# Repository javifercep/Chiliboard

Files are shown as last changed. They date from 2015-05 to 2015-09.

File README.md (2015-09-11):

# Chiliboard
The Chiliboard is an Arduino form factor board with two CAN - 2.0B interfaces. It is based on STM32F105 MCU and can work as an extension of the [Noodleboard](https://github.com/javifercep/Noodleboard). It has been developed for the [MuBA](http://javisfryingchips.com/portfolio/detail/multi-bus-analyzer/) project.

##Features

 * STM32F105RGT6 microcontroller featuring 32-bit ARM Cortex-M3 core,256 KB Flash, 64 KB RAM in an LQFP64 package
 * Extension header fully compatible with Arduino™ form-factor
 * SN65HVD232: CAN transceiver
 * Board power supply: through pin 5 V (Arduino form-factor).
 * Four green user LEDs
 * Reset button
 * Headers for programming and debugging through SWD protocol

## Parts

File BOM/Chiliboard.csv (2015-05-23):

ref | value | footprint | Campo1 | Campo2 | Campo3 | Campo4 | Campo5 | Campo6 | Campo7 | Campo8
C1 | 18 p | ~
C2 | 18 p | ~
C3 | 1u | ~
C4 | 100n | ~
C5 | 100n | ~
C6 | 1u | ~
C7 | 100n | ~
C8 | 100n | ~
C9 | 100n | ~
C10 | 6.8p | ~
C11 | 100n | ~
C12 | 6.8p | ~
C13 | 1u | ~
C14 | 10u | ~
C15 | 10u | ~
C16 | 10u | ~
C17 | 100n | ~
C18 | 100n | ~
C29 | 100n | ~
C32 | 4u7 | ~
CON1 | SWD
D1 | DIODE | ~
D10 | LED | ~
D11 | LED | ~
D12 | LED | ~
D13 | LED | ~
IC1 | LD1117S33 | ~
J1 | DB9
J2 | DB9
JP1 | JUMPER | ~
L1 | fcm1608 | ~
R1 | 0 | ~
R2 | 0 | ~
R3 | 47 | ~
R4 | 10k | ~
R5 | 510 | ~
R6 | 0 | ~
R7 | 0 | ~
R8 | 120 | ~
R9 | 0 | ~
R10 | 120 | ~
R11 | 0 | ~
R12 | 0 | ~
R13 | 0 | ~
R14 | 0 | ~
R15 | 0 | ~
R35 | 510 | ~
R36 | 510 | ~
R37 | 680 | ~
R38 | 680 | ~
SW2 | SW_PUSH | ~
U1 | STM32F105R8 | ~
U2 | ARDUINO_UNO_REDUCED | ~
U3 | SN65HVD232
U4 | SN65HVD232
X1 | 8 MHz | ~
X2 | 32.768 kHz | ~

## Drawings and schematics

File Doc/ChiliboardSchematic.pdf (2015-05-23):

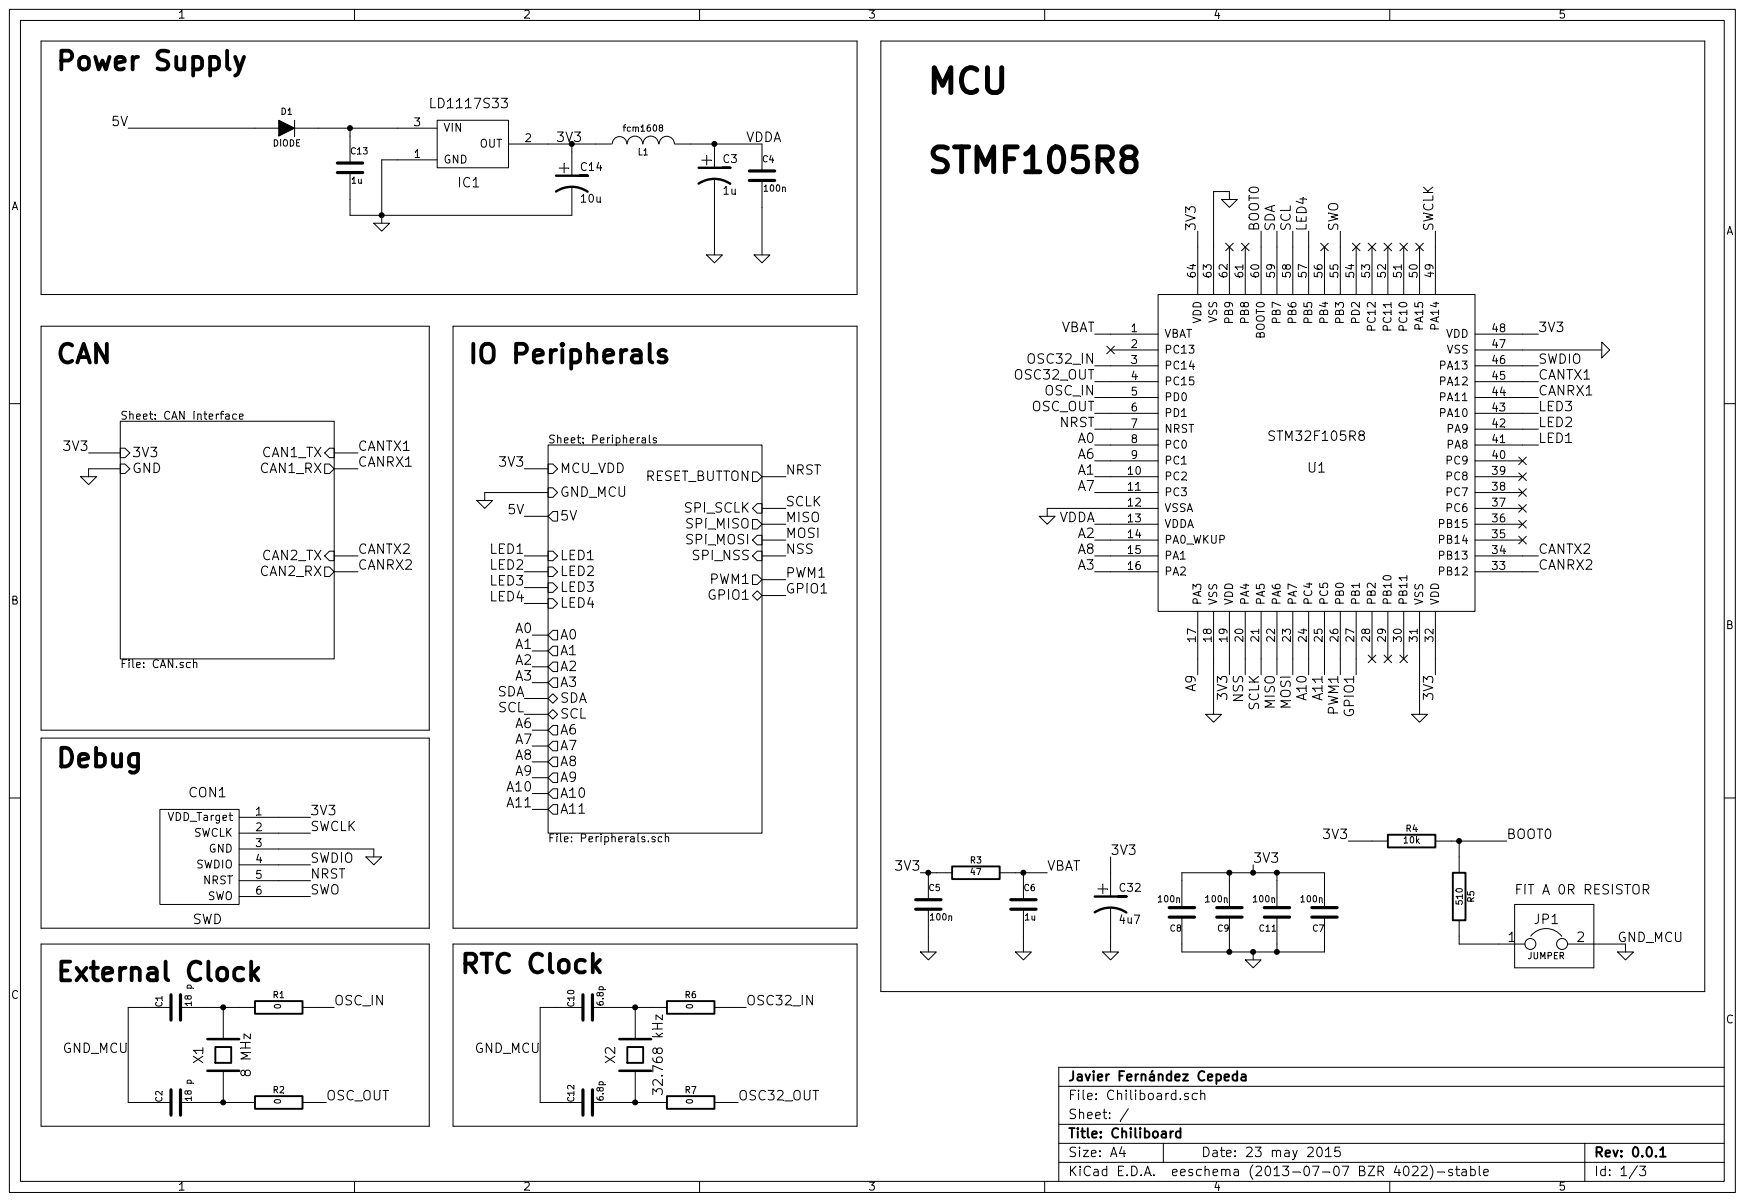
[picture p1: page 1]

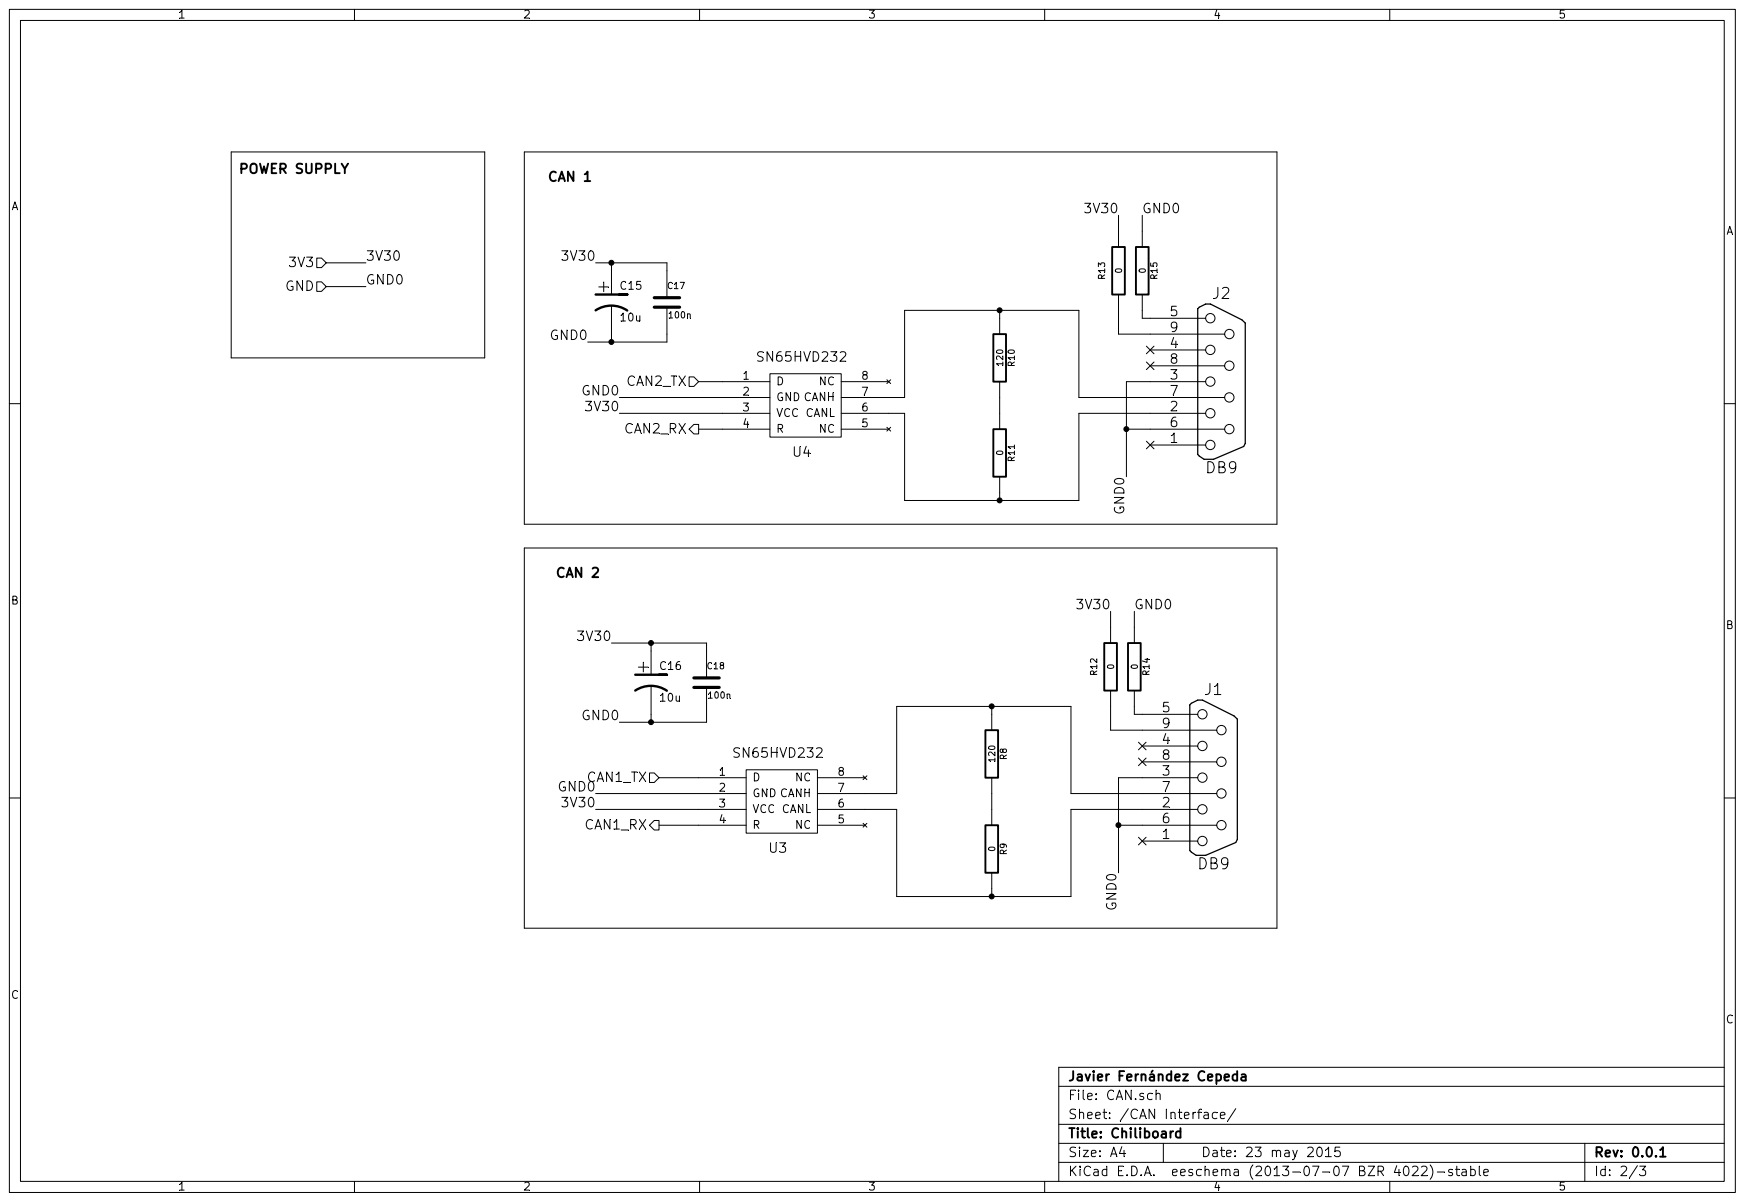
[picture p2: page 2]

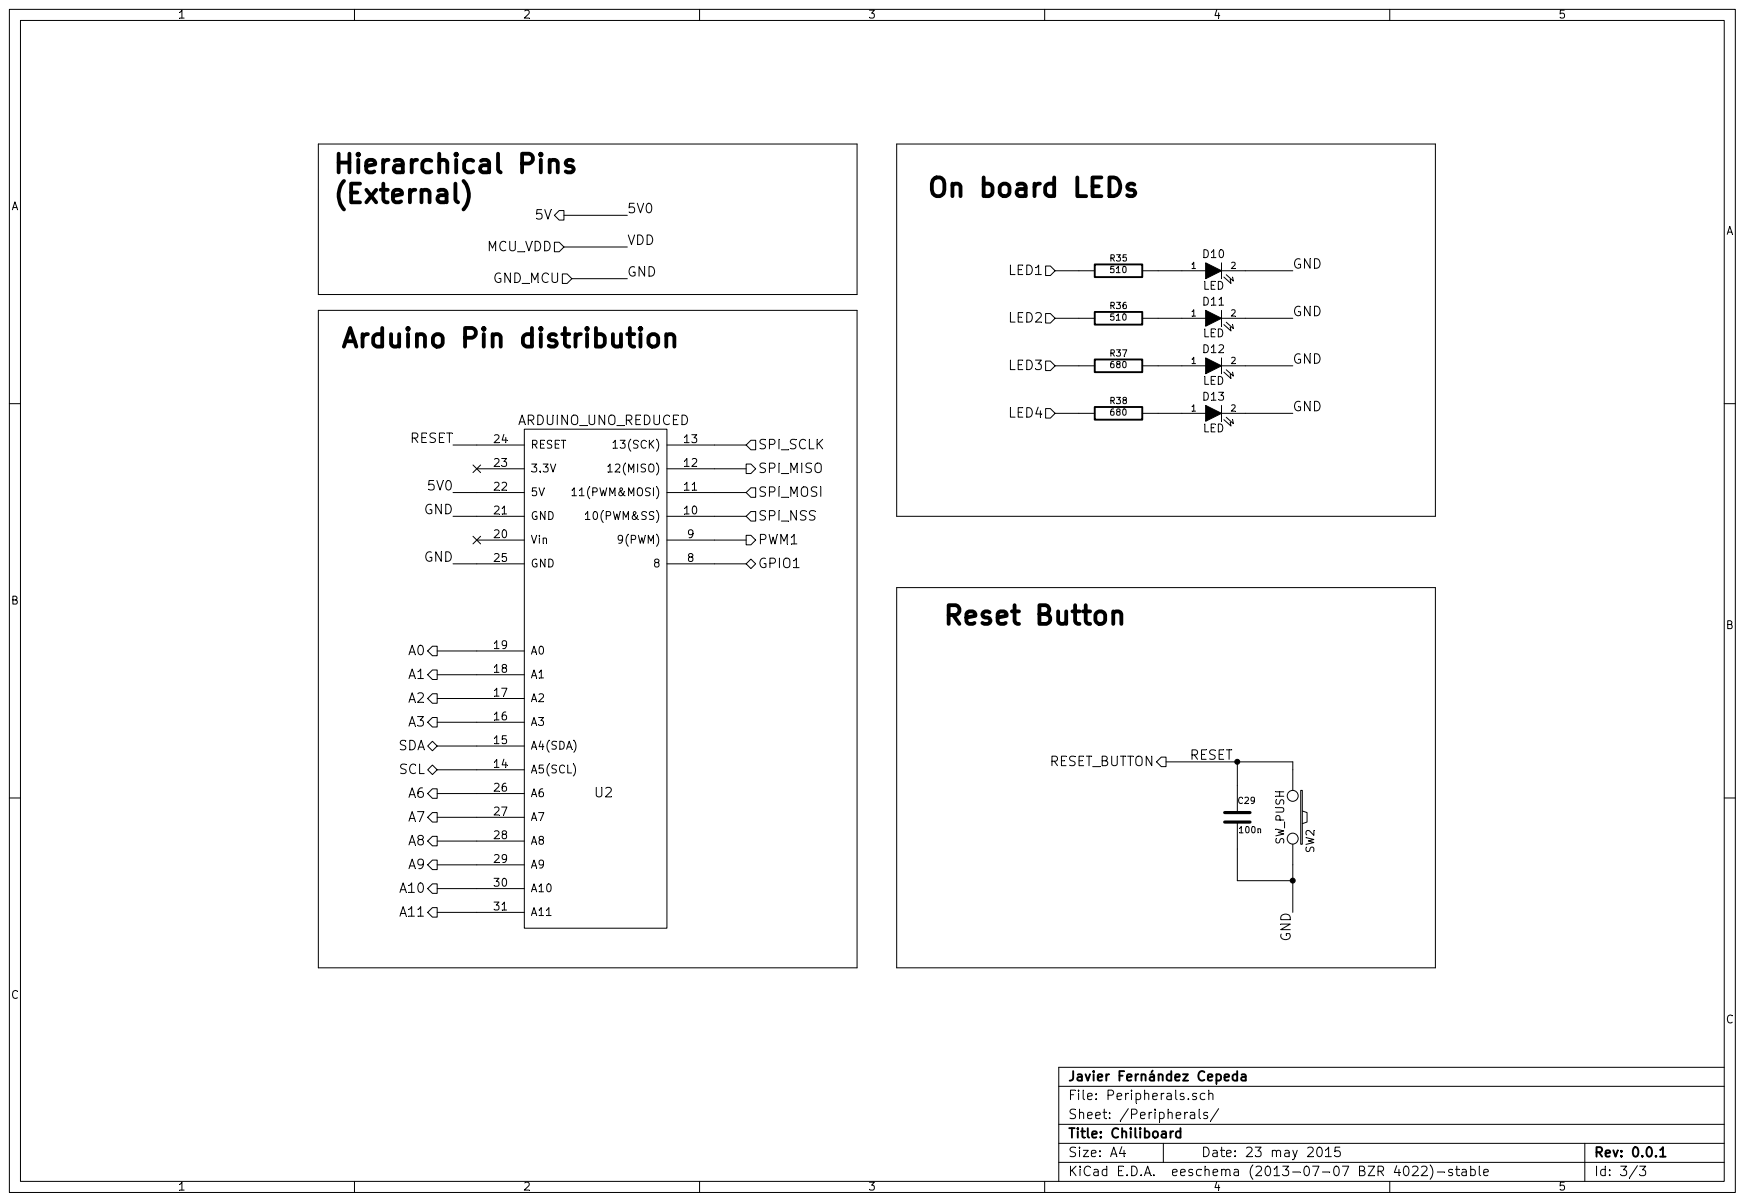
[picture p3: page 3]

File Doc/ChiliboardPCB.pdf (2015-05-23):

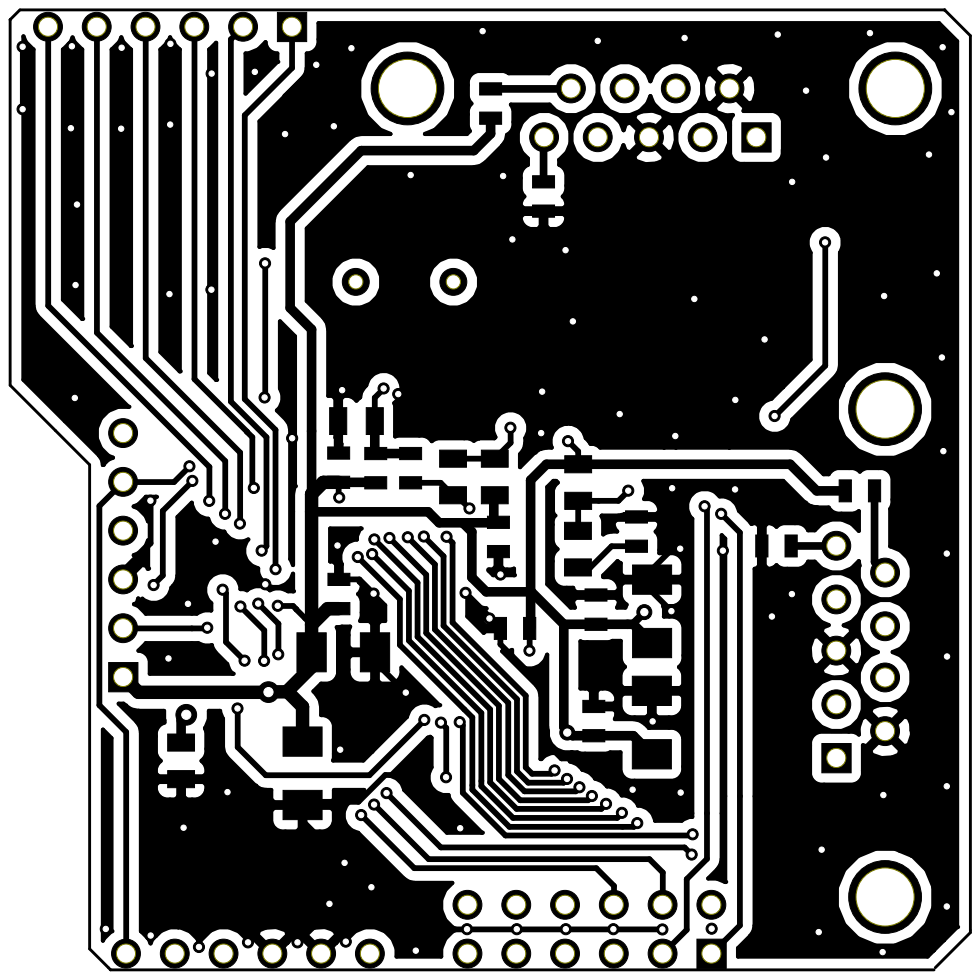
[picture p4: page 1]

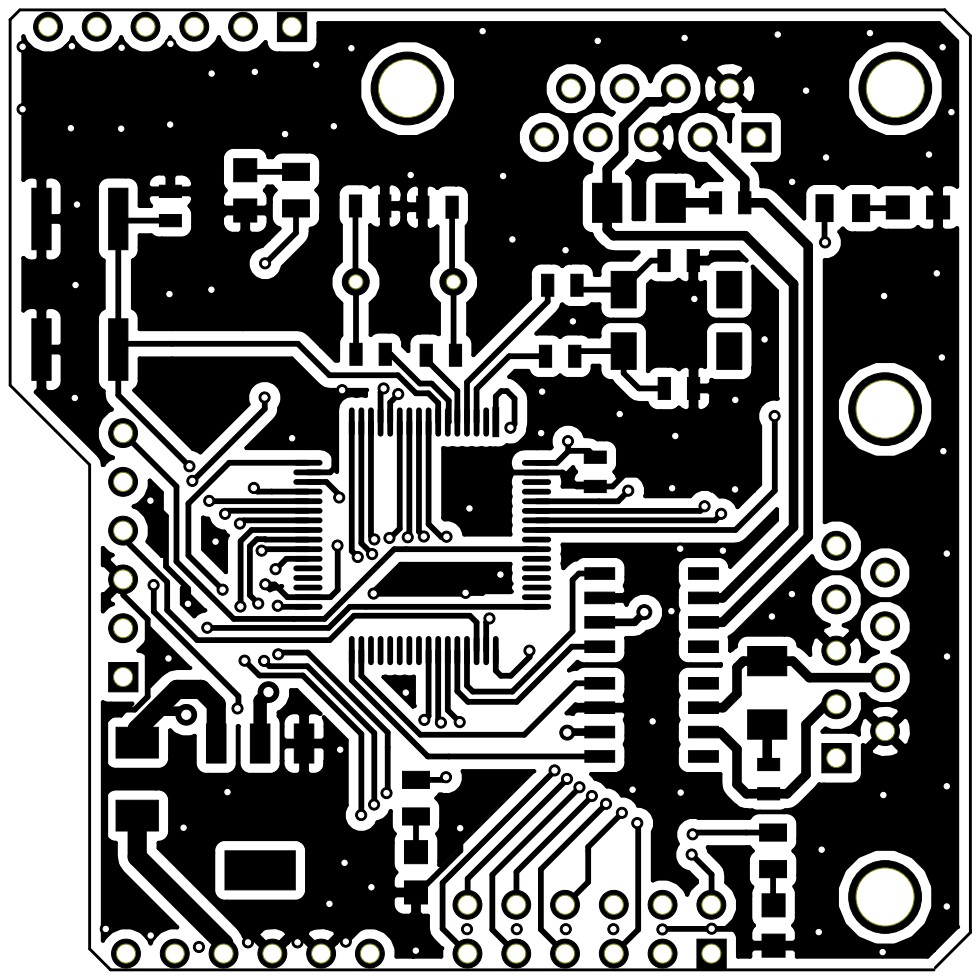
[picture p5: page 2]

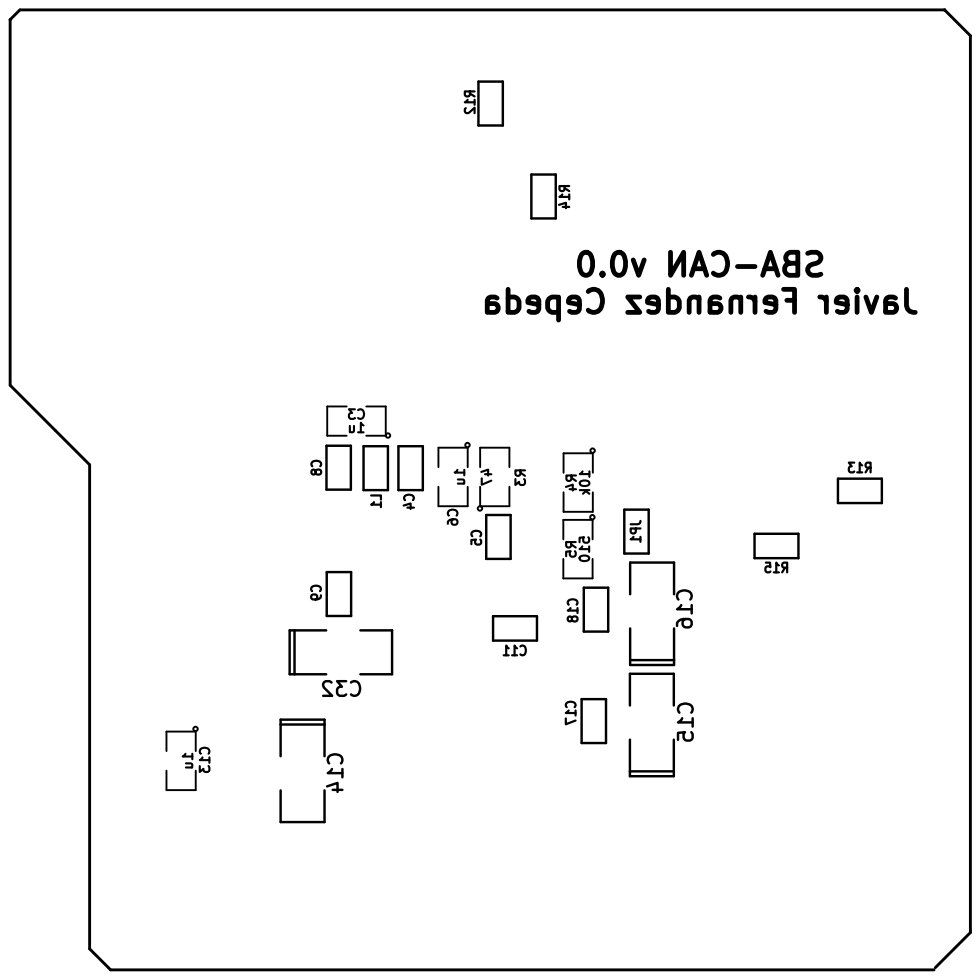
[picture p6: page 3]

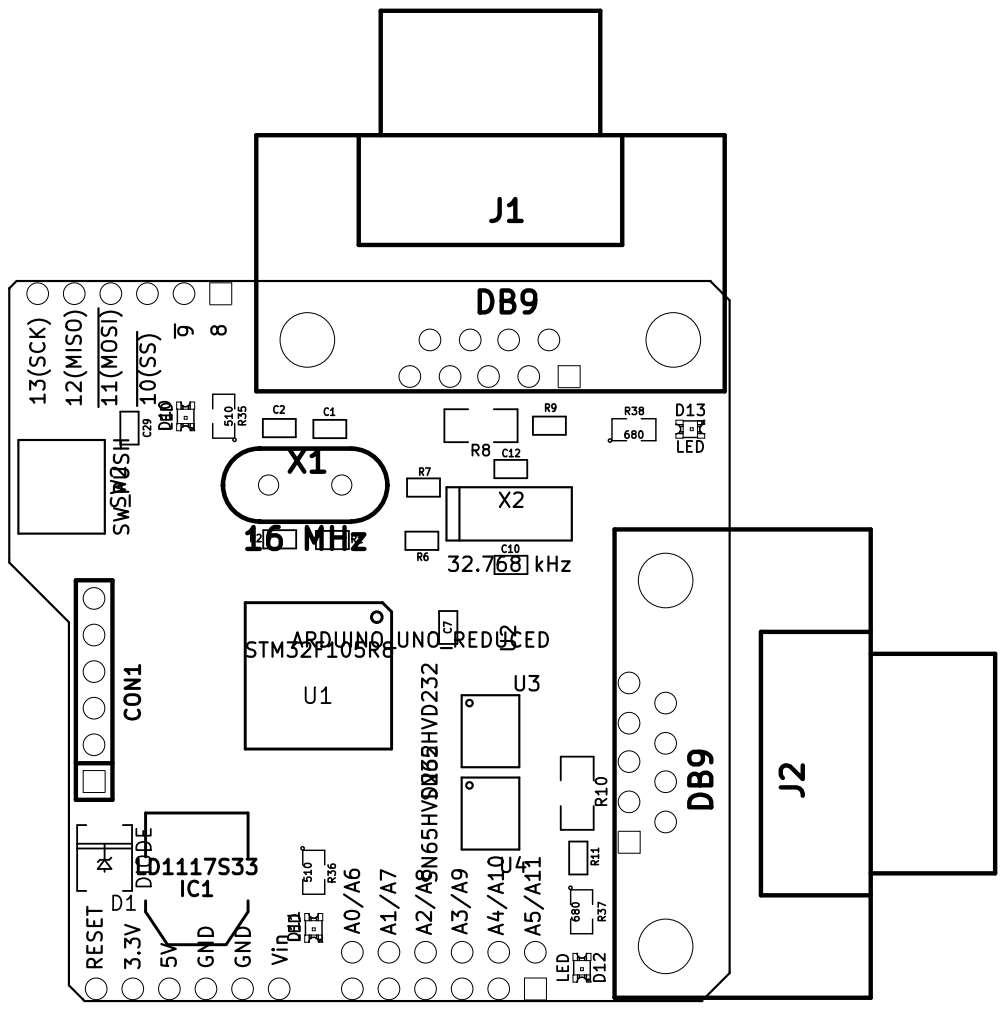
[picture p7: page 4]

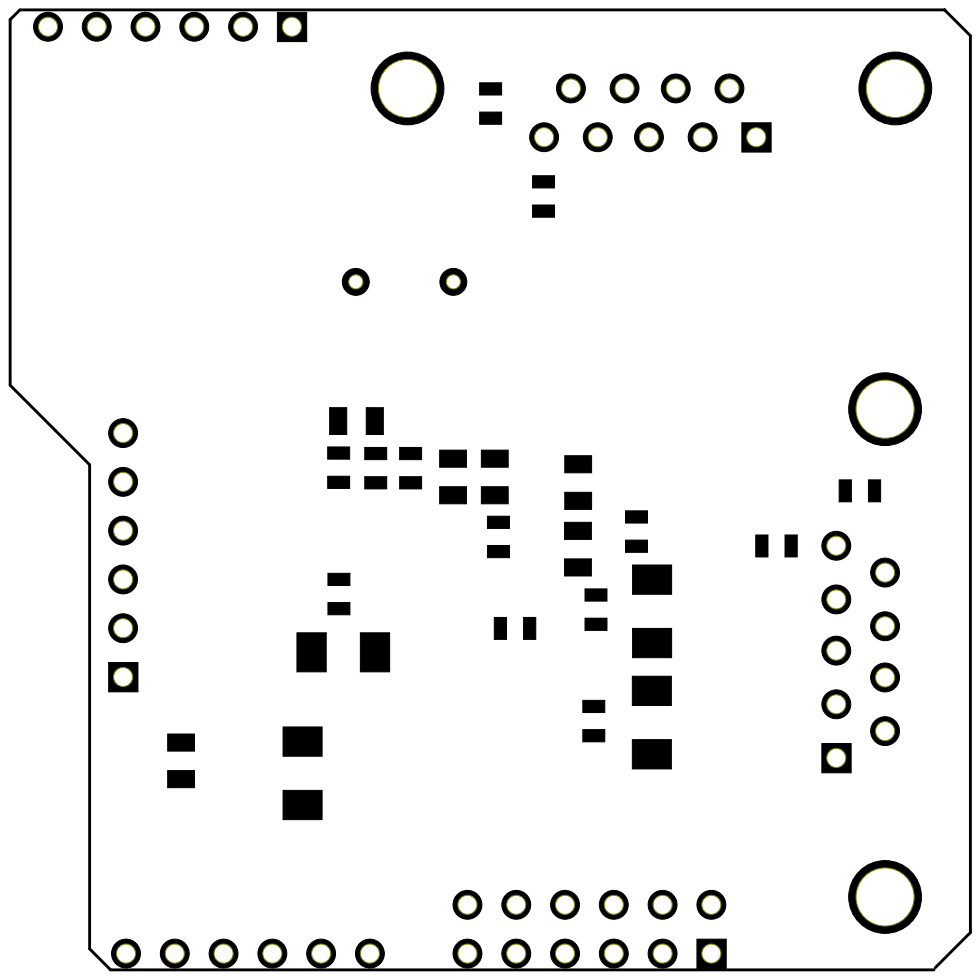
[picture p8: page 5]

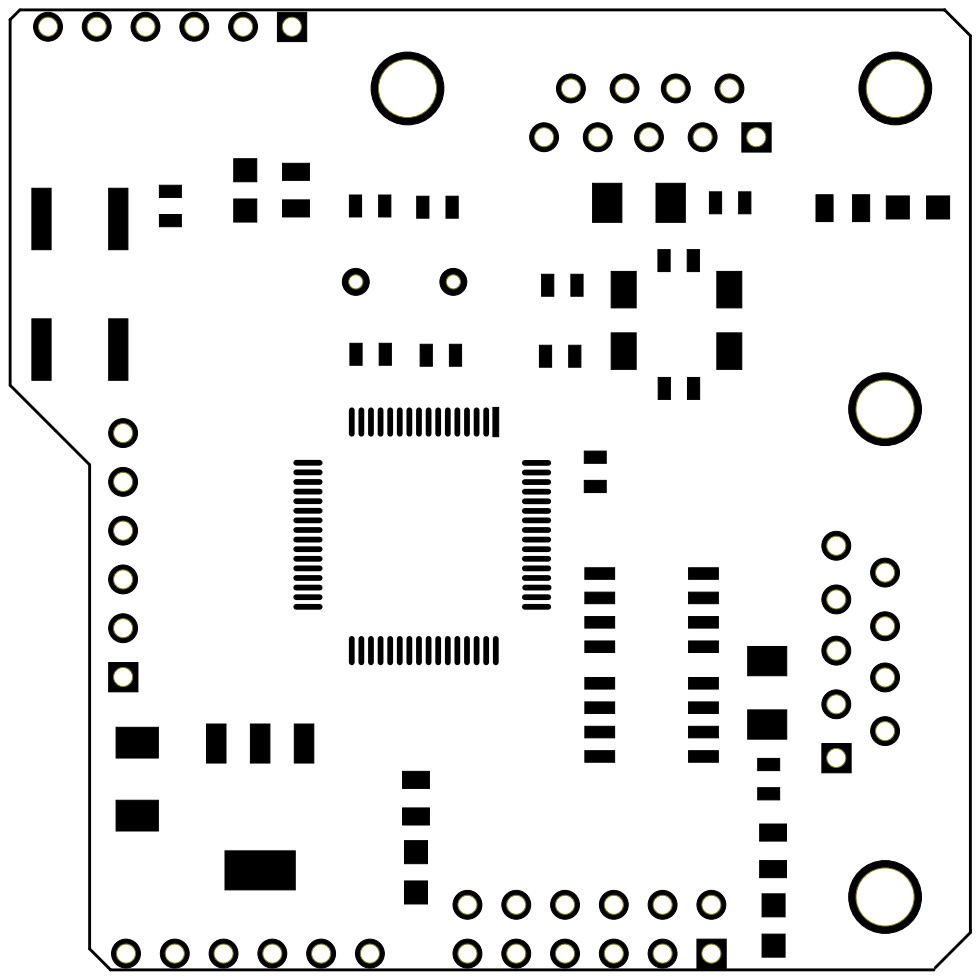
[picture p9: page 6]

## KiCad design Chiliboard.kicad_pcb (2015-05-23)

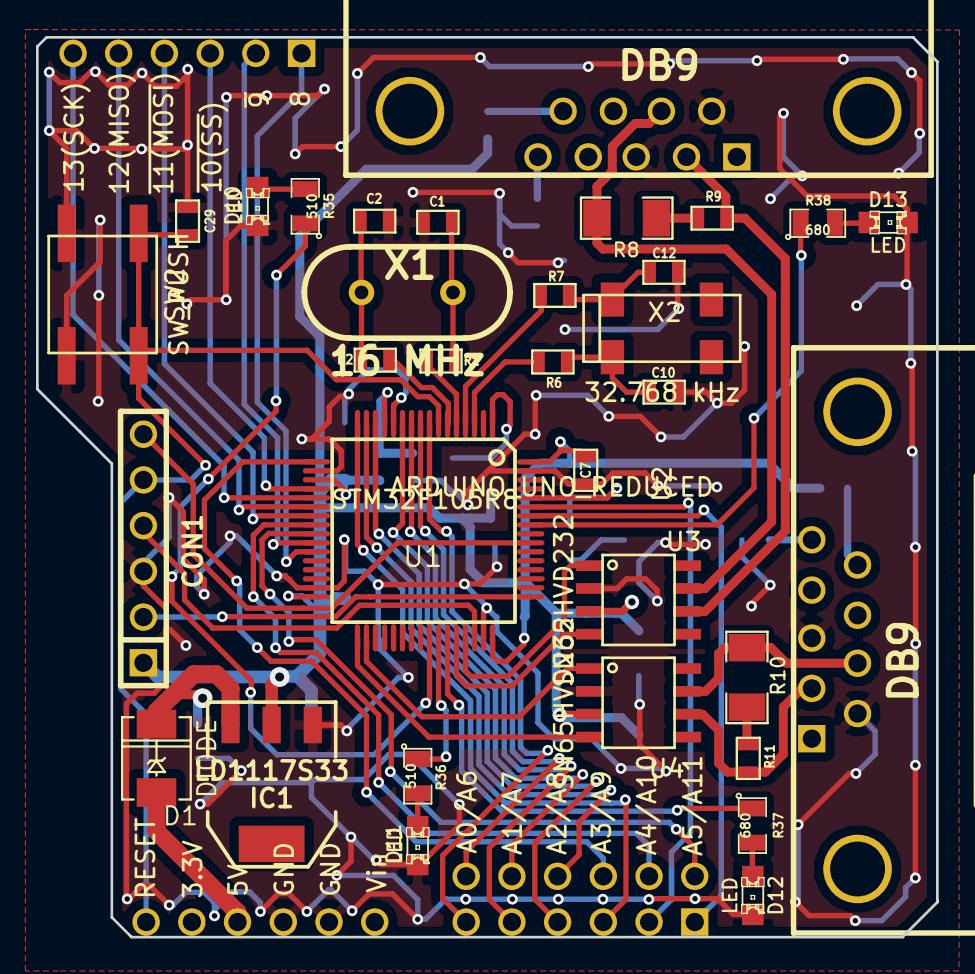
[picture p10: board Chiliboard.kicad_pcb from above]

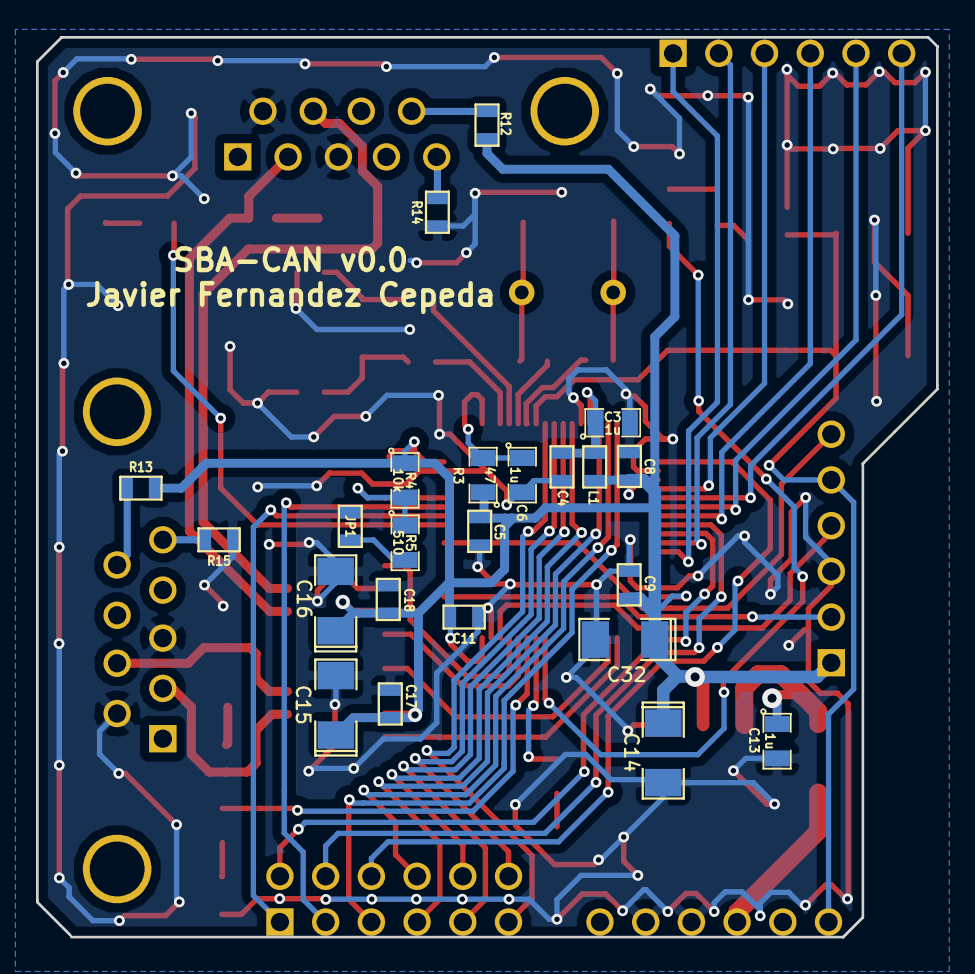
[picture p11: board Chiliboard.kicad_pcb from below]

Board: 2 copper layers, 50.0 x 50.0 mm, 57 parts (23 on the bottom side), 60 nets.

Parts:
C1, C2: 4.7p; SM0603
C3, C6, C13: 1u; SM0805
C4, C5, C7, C8, C9, C11, C17, C18, C29: 100n; SM0603
C10, C12: 6.8p; SM0603
C14, C15, C16: 10u; SM1206POL
C32: 4u7; SM1206POL
CON1: SWD; PIN_ARRAY-6X1
D1: DIODE; DO-214AC(SMA)
D10, D11, D12, D13: LED; LED-0805
IC1: LD1117S33; SOT223
J1, J2: DB9; DB9MC
JP1: JUMPER; SM0603
L1: fcm1608; SM0603
R1, R2, R6, R7, R9, R11, R12, R13, R14, R15: 0; SM0603
R3: 47; SM0805
R4: 10k; SM0805
R5, R35, R36: 510; SM0805
R8, R10: 120; SM1206
R37, R38: 680; SM0805
SW2: SW_PUSH; EVQP0
U1: STM32F105R8; LQFP64
U2: ARDUINO_UNO_REDUCED; ArduinoUNOShieldReduced
U3, U4: SN65HVD232; SOIC8
X1: 16 MHz; HC-49V
X2: 32.768 kHz; RTC

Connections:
/BOOT0: R4.2, R5.1, U1.60
/CAN Interface/3V3: C5.1, C7.2, C8.2, C9.2, C11.2, C14.1, C15.1, C16.1, C17.1, C18.1, C32.1, CON1.1, IC1.2, L1.1, R3.1, R4.1, R12.1, R13.1, U1.19, U1.32, U1.48, U1.64, U3.3, U4.3
/CAN Interface/CAN1_RX: U1.44, U3.4
/CAN Interface/CAN1_TX: U1.45, U3.1
/CAN Interface/CAN2_RX: U1.33, U4.4
/CAN Interface/CAN2_TX: U1.34, U4.1
/OSC32_IN: R6.2, U1.3
/OSC32_OUT: R7.2, U1.4
/OSC_IN: R1.2, U1.5
/OSC_OUT: R2.2, U1.6
/Peripherals/5V: D1.1, U2.22
/Peripherals/A0: U1.8, U2.19
/Peripherals/A1: U1.10, U2.18
/Peripherals/A2: U1.14, U2.17
/Peripherals/A3: U1.16, U2.16
/Peripherals/A6: U1.9, U2.26
/Peripherals/A7: U1.11, U2.27
/Peripherals/A8: U1.15, U2.28
/Peripherals/A9: U1.17, U2.29
/Peripherals/A10: U1.24, U2.30
/Peripherals/A11: U1.25, U2.31
/Peripherals/GPIO1: U1.27, U2.8
/Peripherals/LED1: R35.1, U1.41
/Peripherals/LED2: R36.1, U1.42
/Peripherals/LED3: R37.1, U1.43
/Peripherals/LED4: R38.1, U1.57
/Peripherals/PWM1: U1.26, U2.9
/Peripherals/RESET_BUTTON: C29.1, CON1.5, SW2.1, U1.7, U2.24
/Peripherals/SCL: U1.58, U2.14
/Peripherals/SDA: U1.59, U2.15
/Peripherals/SPI_MISO: U1.22, U2.12
/Peripherals/SPI_MOSI: U1.23, U2.11
/Peripherals/SPI_NSS: U1.20, U2.10
/Peripherals/SPI_SCLK: U1.21, U2.13
/SWCLK: CON1.2, U1.49
/SWDIO: CON1.4, U1.46
/SWO: CON1.6, U1.55
/VBAT: C6.1, R3.2, U1.1
/VDDA: C3.1, C4.1, L1.2, U1.13
GND: C1.1, C2.1, C3.2, C4.2, C5.2, C6.2, C7.1, C8.1, C9.1, C10.1, C11.1, C12.1, C13.2, C14.2, C15.2, C16.2, C17.2, C18.2, C29.2, C32.2, CON1.3, D10.2, D11.2, D12.2, D13.2, IC1.1, J1.3, J1.6, J2.3, J2.6, JP1.2, R14.1, R15.1, SW2.2, U1.12, U1.18, U1.31, U1.47, U1.63, U2.21, U2.25, U3.2, U4.2
unnamed: C10.2, R6.1, X2.2
unnamed: C12.2, R7.1, X2.1
unnamed: JP1.1, R5.2
unnamed: C1.2, R1.1, X1.2
unnamed: C2.2, R2.1, X1.1
unnamed: C13.1, D1.2, IC1.3
unnamed: D10.1, R35.2
unnamed: D11.1, R36.2
unnamed: D13.1, R38.2
unnamed: D12.1, R37.2
unnamed: R10.2, R11.1
unnamed: J1.2, R9.2, U3.6
unnamed: J1.7, R8.1, U3.7
unnamed: J2.5, R15.2
unnamed: J2.9, R13.2
unnamed: J1.9, R12.2
unnamed: J1.5, R14.2
unnamed: J2.7, R10.1, U4.7
unnamed: R8.2, R9.1
unnamed: J2.2, R11.2, U4.6

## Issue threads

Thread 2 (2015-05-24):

Include a connector for external power supply

javifercep, 2015-05-24:
La implementación actual sólo puede ser alimentado por una Noodleboard o simulando la 5V en los encabezados de "poder". Un conector con tornillos o algo como esto va a ser mejor.
